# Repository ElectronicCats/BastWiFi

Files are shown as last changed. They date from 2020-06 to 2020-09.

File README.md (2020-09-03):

# BastWiFi

## License

OpenSourceLicense

Electronic Cats invests time and resources providing this open source design, please support Electronic Cats and open-source hardware by purchasing products from Electronic Cats!

Designed by Electronic Cats.

Firmware released under an GNU AGPL v3.0 license. See the LICENSE file for more information.

Hardware released under an CERN Open Hardware Licence v1.2. See the LICENSE_HARDWARE file for more information.

Electronic Cats is a registered trademark, please do not use if you sell these PCBs.

Jun 2020

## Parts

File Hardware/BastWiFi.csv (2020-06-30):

Source: | C:\Users\Diego Armadillo\Desktop\Bast-ESP32-S2\Hardware\BastWiFi.sch
Date: | 17/06/2020 15:40:54
Tool: | Eeschema (5.1.6)-1
Generator: | C:\Program Files\KiCad\bin\scripting\plugins/bom_csv_grouped_by_value.py
Component Count: | 27
Individual Components:
Item | Qty | Reference(s) | Value | LibPart | Footprint | Datasheet | manf#
 |  | C1 | 10uF | Device:C_Small | Capacitor_SMD:C_0603_1608Metric_Pad1.05x0.95mm_HandSolder | https://lcsc.com/product-detail/Others_YAGEO-CC0603KRX5R6BB106_C326057.html | CC0603KRX5R6BB106
 |  | C2 | 10uF | Device:C_Small | Capacitor_SMD:C_0603_1608Metric_Pad1.05x0.95mm_HandSolder | https://lcsc.com/product-detail/Others_YAGEO-CC0603KRX5R6BB106_C326057.html | CC0603KRX5R6BB106
 |  | C3 | 10uF | Device:C_Small | Capacitor_SMD:C_0603_1608Metric_Pad1.05x0.95mm_HandSolder | https://lcsc.com/product-detail/Others_YAGEO-CC0603KRX5R6BB106_C326057.html | CC0603KRX5R6BB106
 |  | C4 | 10uF | Device:C_Small | Capacitor_SMD:C_0603_1608Metric_Pad1.05x0.95mm_HandSolder | https://lcsc.com/product-detail/Others_YAGEO-CC0603KRX5R6BB106_C326057.html | CC0603KRX5R6BB106
 |  | C5 | 10uF | Device:C_Small | Capacitor_SMD:C_0603_1608Metric_Pad1.05x0.95mm_HandSolder | https://lcsc.com/product-detail/Others_YAGEO-CC0603KRX5R6BB106_C326057.html | CC0603KRX5R6BB106
 |  | C6 | 0.1uF | Device:C_Small | Capacitor_SMD:C_0603_1608Metric_Pad1.05x0.95mm_HandSolder | https://lcsc.com/product-detail/Multilayer-Ceramic-Capacitors-MLCC-SMD-SMT_Walsin-Tech-Corp-0603F104Z160CT_C387984.html | 0603F104Z160CT
 |  | C7 | 1uF | Device:C_Small | Capacitor_SMD:C_0603_1608Metric_Pad1.05x0.95mm_HandSolder | https://www.mouser.mx/ProductDetail/Wurth-Elektronik/885012106022 | 885012106022
 |  | D1 | MBR120 | Diode:MBR340 | Diode_SMD:D_SOD-123F | https://www.mouser.mx/ProductDetail/ON-Semiconductor/MBR120VLSFT3G | MBR120VLSFT3G
 |  | D2 | DONE | Device:LED | Diode_SMD:D_0603_1608Metric_Pad1.05x0.95mm_HandSolder | https://www.mouser.mx/ProductDetail/Wurth-Elektronik/150060VS75000?qs=LlUlMxKIyB1Q1Bi5mQ%2FKLw%3D%3D | 150060VS75000
 |  | J1 | Conn_Battery | Connector_Generic:Conn_02x01 | Connector_JST:JST_PH_B2B-PH-SM4-TB_1x02-1MP_P2.00mm_Vertical | https://lcsc.com/product-detail/Wire-To-Board-Wire-To-Wire-Connector_JST-Sales-America_B2B-PH-SM4-TB-LF-SN_JST-Sales-America-B2B-PH-SM4-TB-LF-SN_C160352.html | B2B-PH-SM4-TB(LF)(SN)
 |  | J3 | Conn_Left | Connector_Generic:Conn_01x16 | Connector_PinSocket_2.54mm:PinSocket_1x16_P2.54mm_Vertical | ~
 |  | J4 | Conn_Right | Connector_Generic:Conn_01x12 | Connector_PinSocket_2.54mm:PinSocket_1x12_P2.54mm_Vertical | ~
 |  | P1 | USB_C_Plug_USB2.0 | Connector:USB_C_Plug_USB2.0 | Connectors EC:C393939 | https://lcsc.com/product-detail/USB-Connectors_SHOU-HAN-TYPE-C16PIN_C393939.html | TYPE-C16PIN
 |  | Q1 | DMG3415U-7 | Transistor_FET:TP0610L | Package_TO_SOT_SMD:TSOT-23 | https://www.mouser.mx/ProductDetail/Diodes-Incorporated/DMG3415U-7 | DMG3415U-7
 |  | R1 | 2K | Device:R_Small | Resistor_SMD:R_0603_1608Metric_Pad1.05x0.95mm_HandSolder | https://www.mouser.mx/ProductDetail/Vishay-Dale/CRCW06032K00FKEAC | CRCW06032K00FKEAC
 |  | R2 | 100K | Device:R_Small | Resistor_SMD:R_0603_1608Metric_Pad1.05x0.95mm_HandSolder | https://www.mouser.mx/ProductDetail/Vishay-Draloric/RCA0603100KJNEC?qs=DL%2Fp6SVo8Vmly4x%2FMjcyUQ== | RCA0603100KJNEC
 |  | R3 | 1K | Device:R_Small | Resistor_SMD:R_0603_1608Metric_Pad1.05x0.95mm_HandSolder | https://www.mouser.mx/ProductDetail/Panasonic/ERJ-3GEYJ102V?qs=66DK8nO8gJBFiTsClorqsA%3D%3D | ERJ-3GEYJ102V
 |  | R4 | 10K | Device:R_Small | Resistor_SMD:R_0603_1608Metric_Pad1.05x0.95mm_HandSolder | https://www.mouser.mx/ProductDetail/ROHM-Semiconductor/SFR03EZPF1002 | SFR03EZPF1002
 |  | R5 | 5.1K | Device:R_Small | Resistor_SMD:R_0603_1608Metric_Pad1.05x0.95mm_HandSolder | https://www.mouser.mx/ProductDetail/Vishay-Dale/CRCW06035K10FKEAC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 | CRCW06035K10FKEAC
 |  | R6 | 5.1K | Device:R_Small | Resistor_SMD:R_0603_1608Metric_Pad1.05x0.95mm_HandSolder | https://www.mouser.mx/ProductDetail/Vishay-Dale/CRCW06035K10FKEAC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 | CRCW06035K10FKEAC
 |  | R7 | 10K | Device:R_Small | Resistor_SMD:R_0603_1608Metric_Pad1.05x0.95mm_HandSolder | https://www.mouser.mx/ProductDetail/ROHM-Semiconductor/SFR03EZPF1002 | SFR03EZPF1002
 |  | R8 | 10K | Device:R_Small | Resistor_SMD:R_0603_1608Metric_Pad1.05x0.95mm_HandSolder | https://www.mouser.mx/ProductDetail/ROHM-Semiconductor/SFR03EZPF1002 | SFR03EZPF1002
 |  | SW1 | GPIO0 | Switch:SW_Push | Connectors EC:C455281 | https://lcsc.com/product-detail/New-Arrivals_XUNPU-TS-1088R-02526_C455281.html | TS-1088R-02526
 |  | SW2 | RESET | Switch:SW_Push | Connectors EC:C455281 | https://lcsc.com/product-detail/New-Arrivals_XUNPU-TS-1088R-02526_C455281.html | TS-1088R-02526
 |  | U1 | MCP73831-3-OT | Battery_Management:MCP73831-3-OT | Package_TO_SOT_SMD:SOT-23-5 | https://www.mouser.mx/ProductDetail/Microchip-Technology/MCP73831T-2ACI-OT | MCP73831T-2ACI/OT
 |  | U2 | AP2112K-3.3 | Regulator_Linear:AP2112K-3.3 | Package_TO_SOT_SMD:SOT-23-5 | https://www.mouser.mx/ProductDetail/Diodes-Incorporated/AP2112K-33TRG1 | AP2112K-3.3TRG1
 |  | U3 | ESP32-S2-WROVER | BastWiFi-rescue:ESP32-S2-WROVER-RF_Module | RF_Module:ESP32-S2-WROVER | https://www.mouser.mx/ProductDetail/Espressif-Systems/ESP32-S2-WROVER?qs=GBLSl2AkirtEnBxrL0jqTA%3D%3D | ESP32-S2-WROVER
Collated Components:
Item | Qty | Reference(s) | Value | LibPart | Footprint | Datasheet | manf#
1 | 5 | C1, C2, C3, C4, C5 | 10uF | Device:C_Small | Capacitor_SMD:C_0603_1608Metric_Pad1.05x0.95mm_HandSolder | https://lcsc.com/product-detail/Others_YAGEO-CC0603KRX5R6BB106_C326057.html | CC0603KRX5R6BB106
2 | 1 | C6 | 0.1uF | Device:C_Small | Capacitor_SMD:C_0603_1608Metric_Pad1.05x0.95mm_HandSolder | https://lcsc.com/product-detail/Multilayer-Ceramic-Capacitors-MLCC-SMD-SMT_Walsin-Tech-Corp-0603F104Z160CT_C387984.html | 0603F104Z160CT
3 | 1 | C7 | 1uF | Device:C_Small | Capacitor_SMD:C_0603_1608Metric_Pad1.05x0.95mm_HandSolder | https://www.mouser.mx/ProductDetail/Wurth-Elektronik/885012106022 | 885012106022
4 | 1 | D1 | MBR120 | Diode:MBR340 | Diode_SMD:D_SOD-123F | https://www.mouser.mx/ProductDetail/ON-Semiconductor/MBR120VLSFT3G | MBR120VLSFT3G
5 | 1 | D2 | DONE | Device:LED | Diode_SMD:D_0603_1608Metric_Pad1.05x0.95mm_HandSolder | https://www.mouser.mx/ProductDetail/Wurth-Elektronik/150060VS75000?qs=LlUlMxKIyB1Q1Bi5mQ%2FKLw%3D%3D | 150060VS75000
6 | 1 | J1 | Conn_Battery | Connector_Generic:Conn_02x01 | Connector_JST:JST_PH_B2B-PH-SM4-TB_1x02-1MP_P2.00mm_Vertical | https://lcsc.com/product-detail/Wire-To-Board-Wire-To-Wire-Connector_JST-Sales-America_B2B-PH-SM4-TB-LF-SN_JST-Sales-America-B2B-PH-SM4-TB-LF-SN_C160352.html | B2B-PH-SM4-TB(LF)(SN)
7 | 1 | J3 | Conn_Left | Connector_Generic:Conn_01x16 | Connector_PinSocket_2.54mm:PinSocket_1x16_P2.54mm_Vertical | ~
8 | 1 | J4 | Conn_Right | Connector_Generic:Conn_01x12 | Connector_PinSocket_2.54mm:PinSocket_1x12_P2.54mm_Vertical | ~
9 | 1 | P1 | USB_C_Plug_USB2.0 | Connector:USB_C_Plug_USB2.0 | Connectors EC:C393939 | https://lcsc.com/product-detail/USB-Connectors_SHOU-HAN-TYPE-C16PIN_C393939.html | TYPE-C16PIN
10 | 1 | Q1 | DMG3415U-7 | Transistor_FET:TP0610L | Package_TO_SOT_SMD:TSOT-23 | https://www.mouser.mx/ProductDetail/Diodes-Incorporated/DMG3415U-7 | DMG3415U-7
11 | 1 | R1 | 2K | Device:R_Small | Resistor_SMD:R_0603_1608Metric_Pad1.05x0.95mm_HandSolder | https://www.mouser.mx/ProductDetail/Vishay-Dale/CRCW06032K00FKEAC | CRCW06032K00FKEAC
12 | 1 | R2 | 100K | Device:R_Small | Resistor_SMD:R_0603_1608Metric_Pad1.05x0.95mm_HandSolder | https://www.mouser.mx/ProductDetail/Vishay-Draloric/RCA0603100KJNEC?qs=DL%2Fp6SVo8Vmly4x%2FMjcyUQ== | RCA0603100KJNEC
13 | 1 | R3 | 1K | Device:R_Small | Resistor_SMD:R_0603_1608Metric_Pad1.05x0.95mm_HandSolder | https://www.mouser.mx/ProductDetail/Panasonic/ERJ-3GEYJ102V?qs=66DK8nO8gJBFiTsClorqsA%3D%3D | ERJ-3GEYJ102V
14 | 3 | R4, R7, R8 | 10K | Device:R_Small | Resistor_SMD:R_0603_1608Metric_Pad1.05x0.95mm_HandSolder | https://www.mouser.mx/ProductDetail/ROHM-Semiconductor/SFR03EZPF1002 | SFR03EZPF1002
15 | 2 | R5, R6 | 5.1K | Device:R_Small | Resistor_SMD:R_0603_1608Metric_Pad1.05x0.95mm_HandSolder | https://www.mouser.mx/ProductDetail/Vishay-Dale/CRCW06035K10FKEAC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 | CRCW06035K10FKEAC
16 | 1 | SW1 | GPIO0 | Switch:SW_Push | Connectors EC:C455281 | https://lcsc.com/product-detail/New-Arrivals_XUNPU-TS-1088R-02526_C455281.html | TS-1088R-02526
17 | 1 | SW2 | RESET | Switch:SW_Push | Connectors EC:C455281 | https://lcsc.com/product-detail/New-Arrivals_XUNPU-TS-1088R-02526_C455281.html | TS-1088R-02526
18 | 1 | U1 | MCP73831-3-OT | Battery_Management:MCP73831-3-OT | Package_TO_SOT_SMD:SOT-23-5 | https://www.mouser.mx/ProductDetail/Microchip-Technology/MCP73831T-2ACI-OT | MCP73831T-2ACI/OT
19 | 1 | U2 | AP2112K-3.3 | Regulator_Linear:AP2112K-3.3 | Package_TO_SOT_SMD:SOT-23-5 | https://www.mouser.mx/ProductDetail/Diodes-Incorporated/AP2112K-33TRG1 | AP2112K-3.3TRG1
20 | 1 | U3 | ESP32-S2-WROVER | BastWiFi-rescue:ESP32-S2-WROVER-RF_Module | RF_Module:ESP32-S2-WROVER | https://www.mouser.mx/ProductDetail/Espressif-Systems/ESP32-S2-WROVER?qs=GBLSl2AkirtEnBxrL0jqTA%3D%3D | ESP32-S2-WROVER

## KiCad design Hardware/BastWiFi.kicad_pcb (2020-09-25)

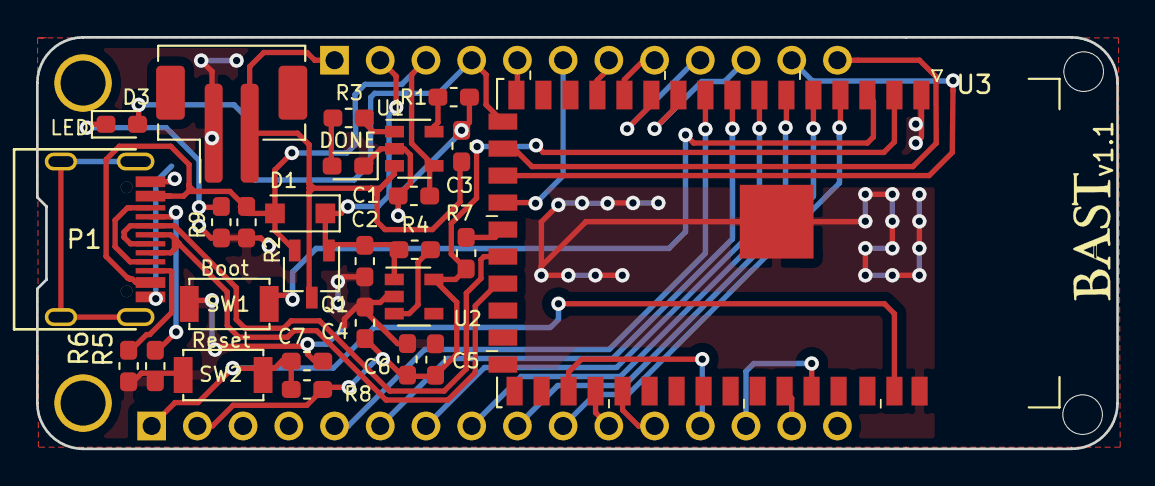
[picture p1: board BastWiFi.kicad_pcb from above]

Board: 2 copper layers, 60.0 x 22.9 mm, 29 parts (0 on the bottom side), 37 nets.

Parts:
C1, C2, C3, C4, C5: 10uF; C_0603_1608Metric_Pad1.05x0.95mm_HandSolder
C6: 0.1uF; C_0603_1608Metric_Pad1.05x0.95mm_HandSolder
C7: 1uF; C_0603_1608Metric_Pad1.05x0.95mm_HandSolder
D1: MBR120; D_SOD-123F
D2: DONE; D_0603_1608Metric_Pad1.05x0.95mm_HandSolder
D3: LED; LED_0603_1608Metric_Pad1.05x0.95mm_HandSolder
J1: Conn_Battery; JST_PH_B2B-PH-SM4-TB_1x02-1MP_P2.00mm_Vertical
J3: Conn_Left; PinSocket_1x16_P2.54mm_Vertical
J4: Conn_Right; PinSocket_1x12_P2.54mm_Vertical
P1: USB_C_Plug_USB2.0; C393939
Q1: DMG3415U-7; TSOT-23
R1: 2K; R_0603_1608Metric_Pad1.05x0.95mm_HandSolder
R2: 100K; R_0603_1608Metric_Pad1.05x0.95mm_HandSolder
R3, R9: 1K; R_0603_1608Metric_Pad1.05x0.95mm_HandSolder
R4, R7, R8: 10K; R_0603_1608Metric_Pad1.05x0.95mm_HandSolder
R5, R6: 5.1K; R_0603_1608Metric_Pad1.05x0.95mm_HandSolder
SW1: GPIO0; C455281
SW2: RESET; C455281
U1: MCP73831-3-OT; SOT-23-5
U2: AP2112K-3.3; SOT-23-5
U3: ESP32-S2-WROVER

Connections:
+3V3: C4.1, C5.1, C6.1, J3.2, R7.1, R8.1, U2.5, U3.2
+BATT: C3.1, J1.2, J4.1, Q1.3, U1.3
/A0: J3.10, U3.4
/A1: J3.9, U3.5
/A2: J3.8, U3.6
/A3: J3.7, U3.7
/A4: J3.6, U3.8
/A5: J3.5, U3.9
/D+: P1.A6, U3.23
/D-: P1.A7, U3.22
/EN: C2.1, D1.1, J4.2, Q1.1, R4.2, U2.1
/GPIO0: SW1.2, U3.3
/GPIO05: J4.10, U3.10
/GPIO06: J4.9, U3.11
/GPIO09: J4.8, U3.12
/GPIO10: J4.7, U3.13
/GPIO11: J4.6, U3.20
/GPIO12: J4.5, U3.16
/GPIO13: D3.2, J4.4, U3.17
/GPIO18: R7.2, U3.21
/MISO: J3.13, U3.29
/MOSI: J3.12, U3.31
/RX: J3.14, U3.38
/SCK: J3.11, U3.30
/SCL: J4.11, U3.19
/SDA: J4.12, U3.18
/TX: J3.15, U3.37
/~RST~: C7.1, J3.1, R8.2, SW2.2, U3.41
GND: C1.2, C2.2, C3.2, C4.2, C5.2, C6.2, C7.2, D2.1, J1.1, J3.4, P1.A1, R1.2, R2.2, R5.1, R6.1, R9.2, SW1.1, SW2.1, U1.2, U2.2, U3.1, U3.26, U3.42, U3.43
unnamed: D2.2, R3.2
unnamed: D3.1, R9.1
unnamed: P1.A5, R5.2
unnamed: P1.B5, R6.2
unnamed: R1.1, U1.5
unnamed: R3.1, U1.1
unnamed: R4.1, U2.3
VBUS: C1.1, D1.2, J4.3, P1.A4, Q1.2, R2.1, U1.4

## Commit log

2020-04-25 init schematic and PCB
    [BastWiFi.kicad_pcb, BastWiFi.sch]
2020-06-02 Change footprint sw
    [BastWiFi.kicad_pcb, BastWiFi.sch]
2020-06-05 Add connector
    [BastWiFi.kicad_pcb, BastWiFi.sch]
2020-06-10 Change tracks
    [BastWiFi.kicad_pcb]
2020-06-10 Add change sch
    [BastWiFi.sch]
2020-06-11 Add button
    [BastWiFi.kicad_pcb, BastWiFi.sch]
2020-06-11 Change button
    [BastWiFi.kicad_pcb]
2020-06-11 Change sch
    [BastWiFi.sch]
2020-06-13 Change footprint
    [BastWiFi.kicad_pcb, BastWiFi.sch]
2020-06-15 update schematic
    [BastWiFi.kicad_pcb, BastWiFi.sch]
2020-06-16 add LED
    [BastWiFi.sch]
2020-06-16 BOM added
2020-06-30 Change Rev
    [BastWiFi.sch]
2020-07-03 Last Revision
    [BastWiFi.kicad_pcb]
2020-07-09 Change pin
    [BastWiFi.kicad_pcb, BastWiFi.sch]
2020-08-06 change pads
    [BastWiFi.kicad_pcb]
2020-09-23 3D Model
    [BastWiFi.kicad_pcb]
